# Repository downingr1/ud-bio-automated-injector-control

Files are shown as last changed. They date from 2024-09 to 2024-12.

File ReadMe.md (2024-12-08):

# **UD Automated Stereotaxic Injector**

 

> [Arduino Uno Wiring Diagram - Tinkercad](https://www.tinkercad.com/things/jYT1CjaT22d-november-2024-injector-control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)
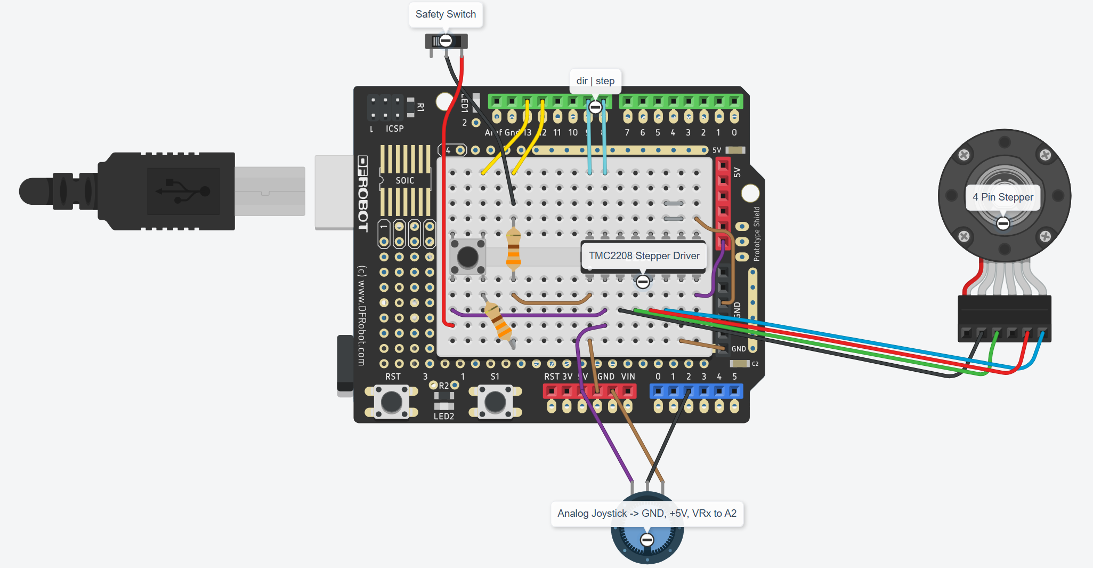
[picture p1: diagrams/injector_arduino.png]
 

This project has been developed by Owen Beer, Reilly Downing, and Megan LaBelle in support of Dr. Aaron Sathyanesan, Dr. Krishna Kidambi, and Mr. Abbas Raza with the University of Dayton Biology and Mechanical Engineering departments.

The Automated Injector is constructed with 3D printed housings, a Nema 8 stepper, an  Arduino starter kit, and various hardware. A full parts list is available as a part of this package.

### Purpose
Stereotaxic surgeries are a very common procedure in modern neuroscience. The University of Dayton Biology Department uses a GCaMP6f Ca2+ sensor to image the firing of neurons after injecting a virus into the brain of a living specimen. This virus causes the calcium indicators (GCaMP6f Ca2+) to be present, which can then be imaged using a specific wavelength laser. The injection of the virus however must be a very controlled process to avoid harming the specimen. Commonly, labs will buy syringe pumps with controllers that run around $3,000. The University of Dayton Biology department has assigned the team the task of designing this open-source alternative solution using readily available, cost-efficient components and an Arduino microcontroller.

### Repository Layout
This repository follows a simple structure.
  - The `diagrams` folder holds diagrams for wiring the arduino control board to the motor and switches. 
  - The `documentation` folder holds the spec sheet for the NEMA 8 Stepper motor as well as the assembly procedure for the automated injector.
  - The `injector_control_ino` folder contains the code used to program the arduino.
  - The `models` folder contains the CAD files used to design and print the injector housing
  - The `readme_images` folder contains the images shown below.

### Programming Arduino Using the Arduino IDE
The most user-friendly way to program and communicate with an Arduino is through the Arduino IDE. The latest IDE can be collected from [https://www.arduino.cc/en/software](https://www.arduino.cc/en/software). 

...

### Simply Executing Serial Communication in VS Code 
Reilly Donwing - September 2024

This documentation will detail how to install Microsoft Visual Studio Code and a Serial Monitor extension to simply establish serial communication with the injector.

1. Retrieve the appropriate installer for your operating system from [https://code.visualstudio.com/download](https://code.visualstudio.com/download)   
2. Run the installer, the default location is fine. Changing the location will not affect this process.  
3. Open VS Code  
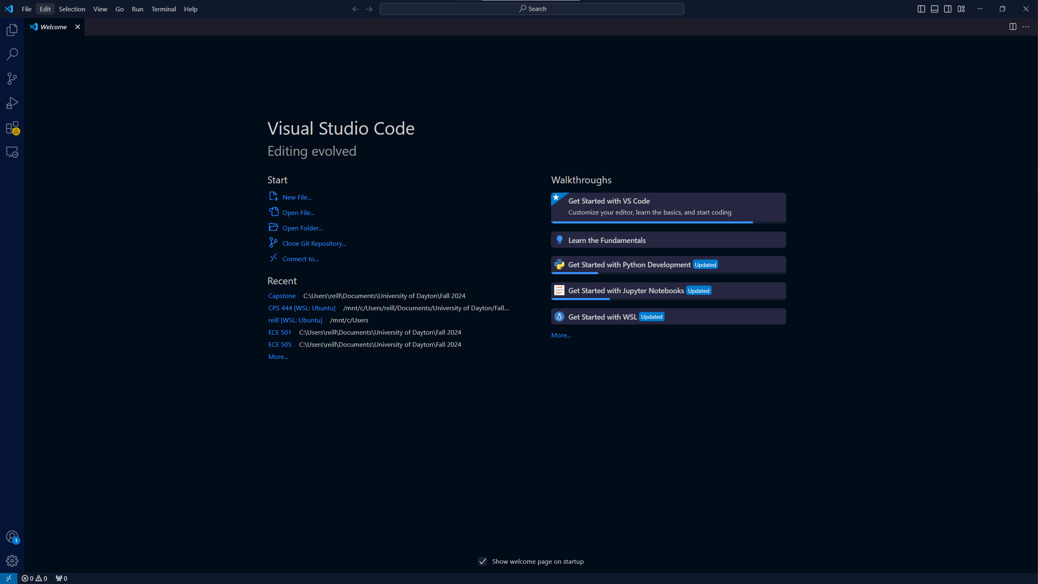
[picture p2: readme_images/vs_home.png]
  
4. Open the extensions menu ( ctrl \+ shift \+ x ) and search for Serial Monitor 
5. Select the extension marked as produced by Microsoft, then select install
6. At the top of the window, select Terminal > New Terminal
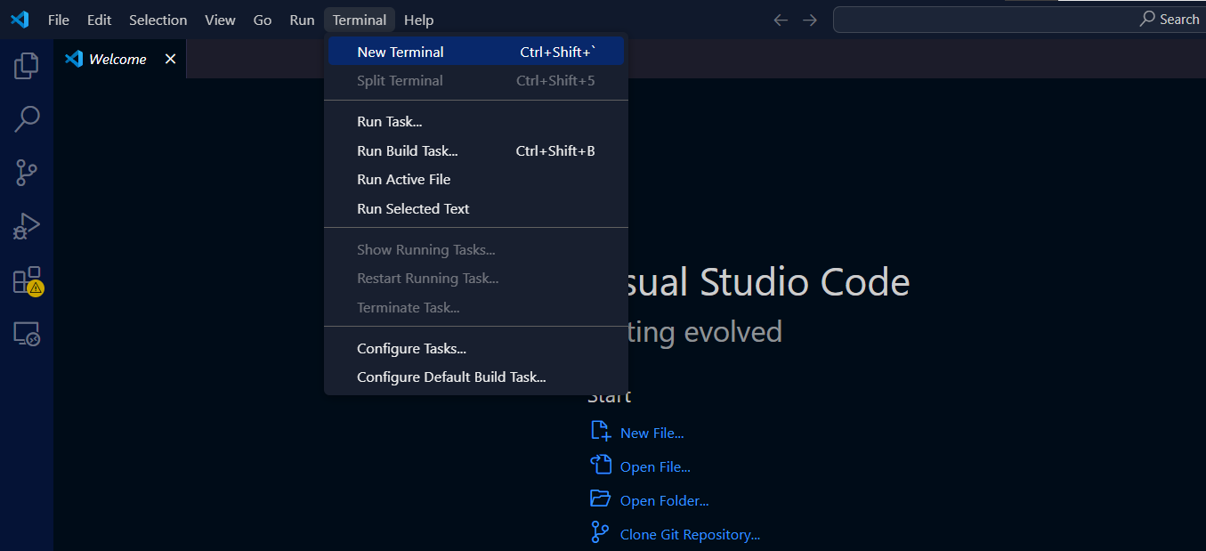
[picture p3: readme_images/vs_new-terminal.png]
  
7. In the new partition at the bottom of the window, select SERIAL MONITOR
8. With the device plugged in, ensure that the Port drop down has the correct port selected, ensure a buad rate of 115200, and select Start Monitoring.

If a message from the device is not displayed, press the reset button (physical button in corner of expansion board) on the Arduino controller.  
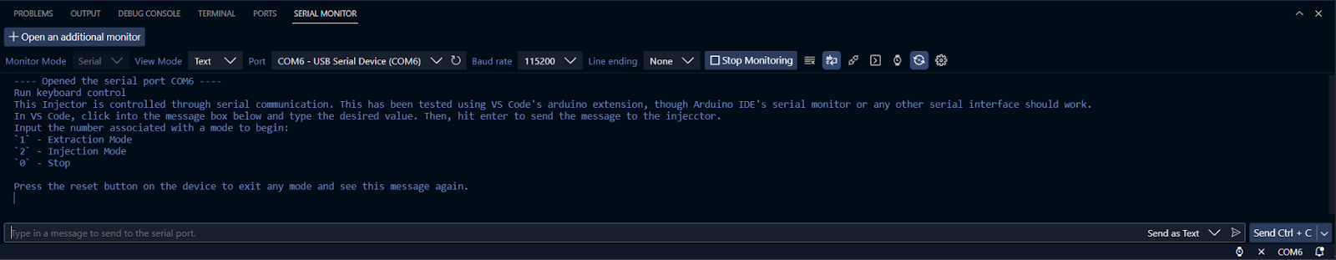
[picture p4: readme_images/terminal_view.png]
  
To send messages and interact with the device, click into the bar at the bottom of the Serial Monitor window. It should read `Type in a message to send to the serial port.` while waiting for an input.

### Programming Arduino in VS Code
Reilly Downing \- April 2024

This documentation will detail how to install Microsoft Visual Studio Code, and how to use the Arduino extension to establish serial communication with the injector.

1. Retrieve the appropriate installer for your operating system from [https://code.visualstudio.com/download](https://code.visualstudio.com/download)   
2. Run the installer, the default location is fine. Changing the location will not affect this process.  
3. Open VS Code  
4. Open the extensions menu ( ctrl \+ shift \+ x ) and search for Arduino  
5. Select the extension marked as produced by Microsoft, then select install  
6. If prompted, select to use Arduino CLI  
   1. If not prompted, open settings ( ctrl \+ , ), type ‘arduino’ into the search bar  
   2. Scroll down to see Arduino: **Use Arduino Cli**  
   3. Select the box to enable this

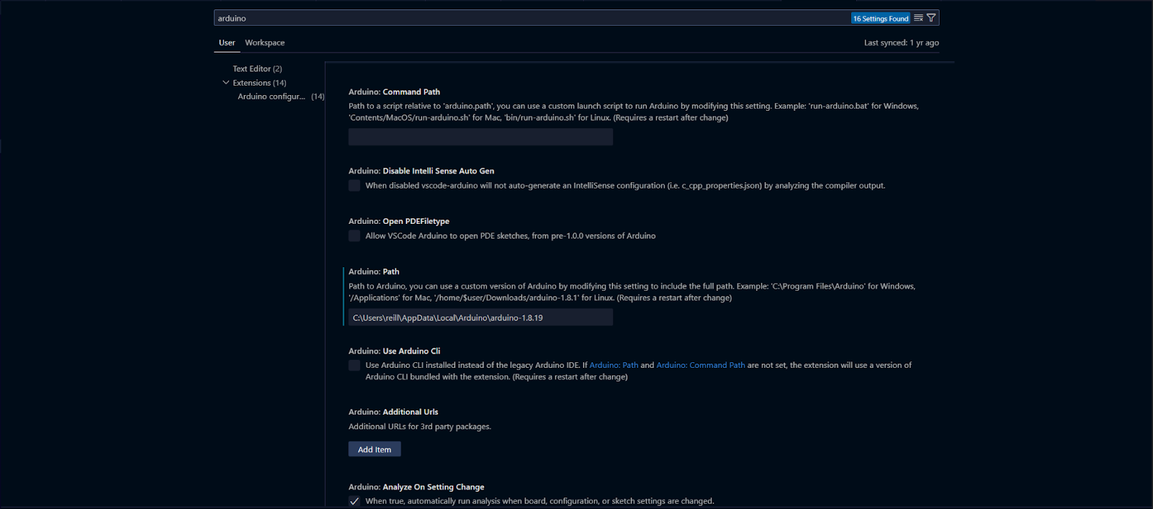
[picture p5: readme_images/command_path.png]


7. Restart the IDE (VS Code)  
8. Ensure the device is plugged into the computer using USB  
   1. Open the command search ( ctrl \+ shift \+ p )  
   2. Begin to type Arduino: Select Serial Port, click the command  
   3. Select the port with Uno R3 or USB Serial Device from the list  
      1. For Error regarding Serial Monitor Extension, return to step 6, double check the CLI use in settings, and restart the IDE, ensuring it has been stopped in task manager before reopening  
      2. if the error pops up after this, simply ignore it and run Arduino: Select Serial Port again  
9. The arduino.json configuration file should be created inside the .vscode directory of the current workspace, ensure this file exists or create it.
   1. Edit the json object to point to the injector control program, it should have the following form:
   ```json
   {
    "board": "arduino:avr:uno",
    "sketch": "injector_control_stepper\\injector_control.ino",
    "port": "COM4"
   }
   ```
10. Open injector_control.ino and select the verify then upload options from the arduino extensions up in the top right of the editor. On errors regarding missing libraries, ensure that the accel_stepper library is included in your arduino libraries path.

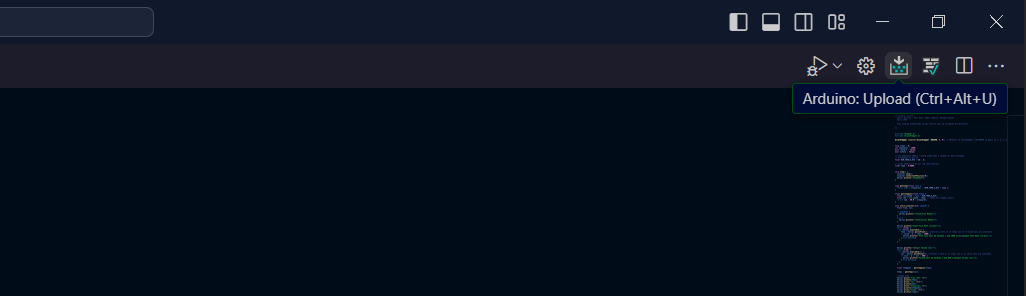
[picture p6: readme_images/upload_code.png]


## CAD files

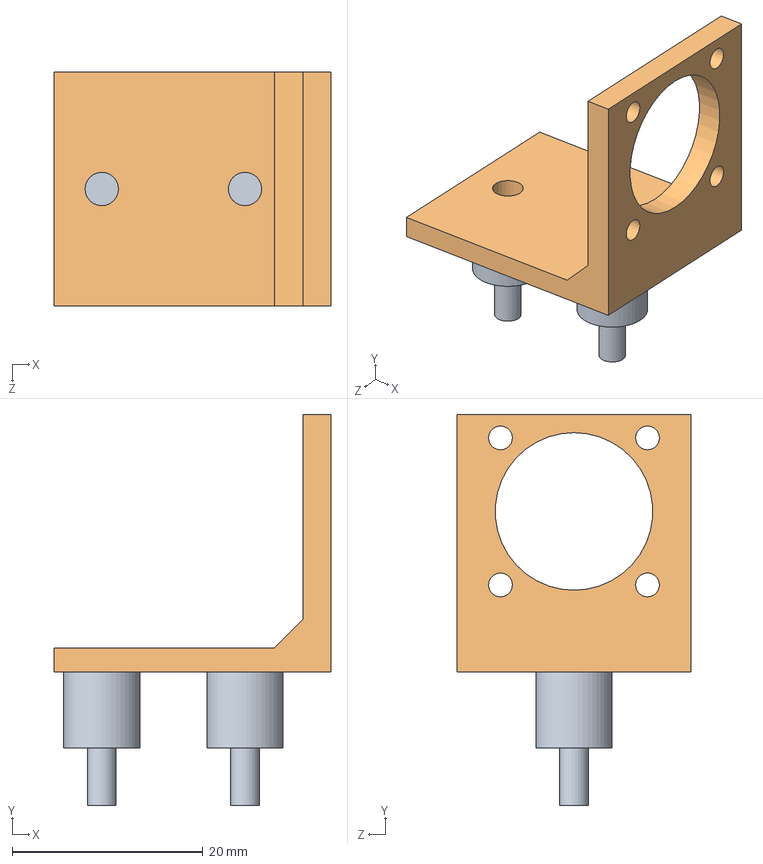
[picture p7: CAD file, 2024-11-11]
models/Currrent/Parts/Assem1.SLDASM
29.0 x 41.0 x 24.5 mm
Nema8 Mount
Vibration Idolator x 2

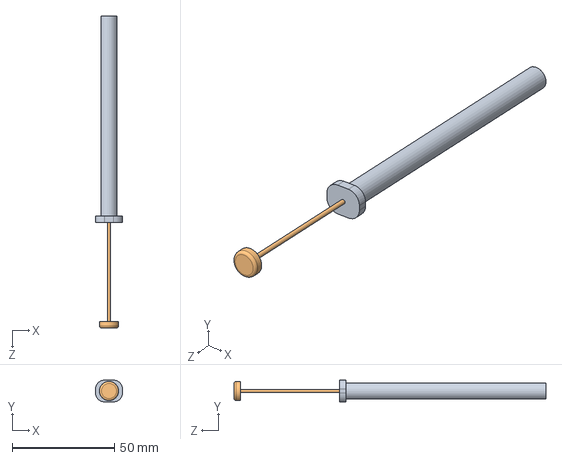
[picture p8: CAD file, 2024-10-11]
models/Currrent/Parts/SyringeAsm.SLDASM
13.2 x 10.7 x 152.3 mm
Plunger
syringe

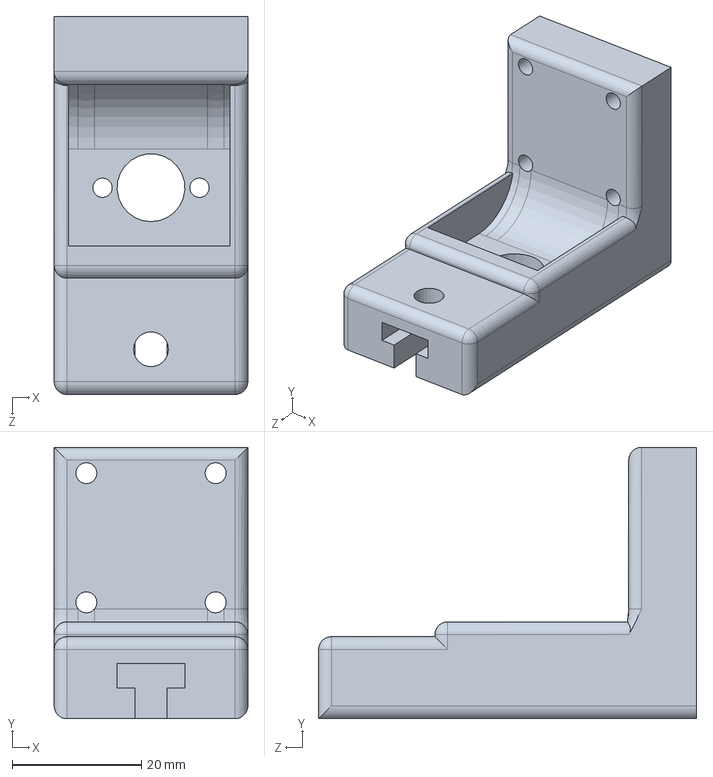
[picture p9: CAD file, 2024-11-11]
models/Currrent/3DPrintedParts/PlungerDriverB.SLDPRT
30.0 x 42.0 x 58.5 mm

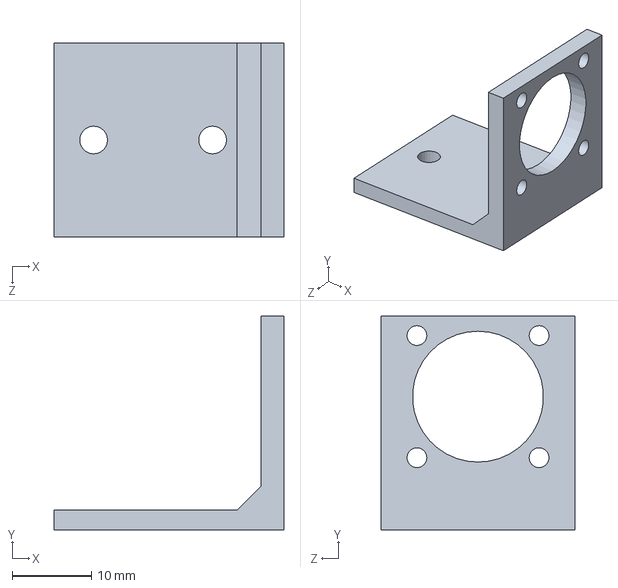
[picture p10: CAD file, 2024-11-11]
models/Currrent/Parts/Nema8 Mount.SLDPRT
29.0 x 27.0 x 24.5 mm

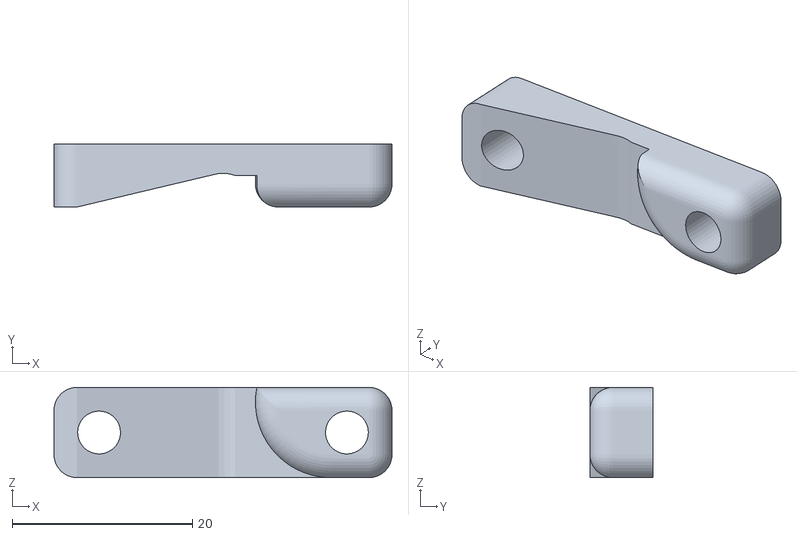
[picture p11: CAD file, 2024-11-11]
STL/RetentionMechanism.STL
37.5 x 7.00 x 10.00

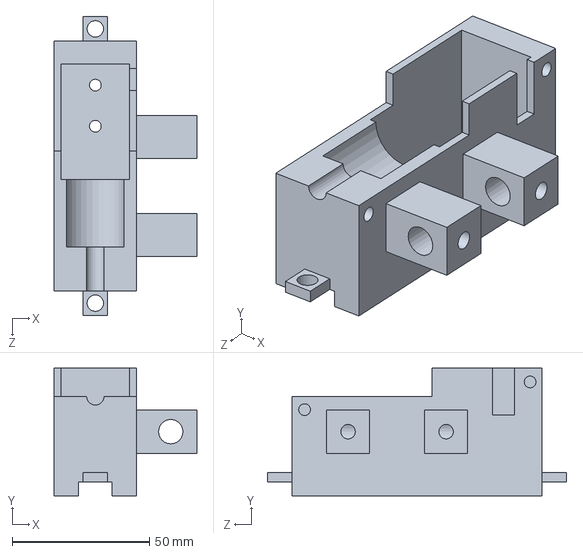
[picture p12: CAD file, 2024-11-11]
models/Currrent/3DPrintedParts/Motor Housing.SLDPRT
52.0 x 46.5 x 109.0 mm

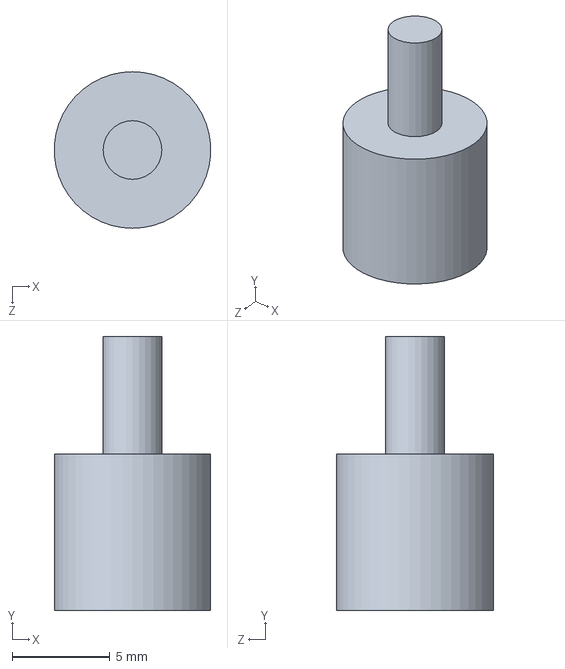
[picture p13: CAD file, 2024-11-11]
models/Currrent/Parts/Vibration Idolator.SLDPRT
7.98 x 14.0 x 8.00 mm

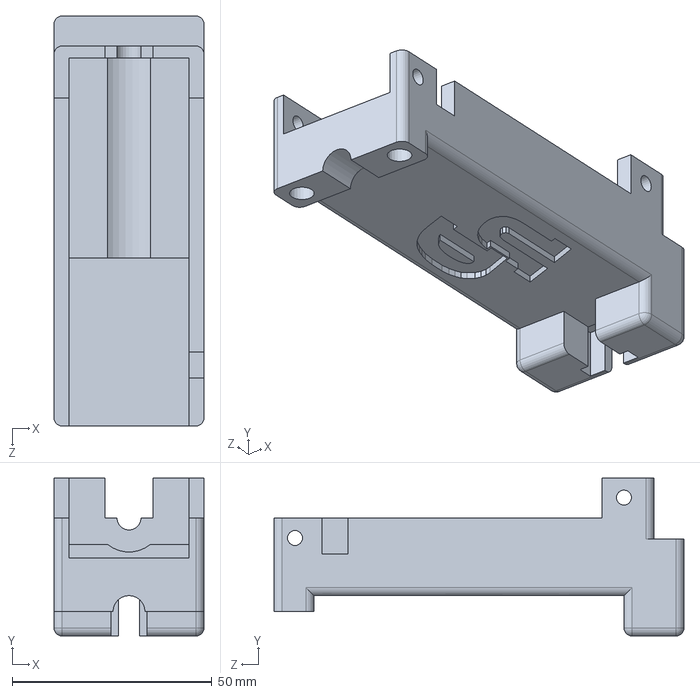
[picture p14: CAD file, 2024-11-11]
models/Currrent/3DPrintedParts/Cover.SLDPRT
37.5 x 39.5 x 102.5 mm

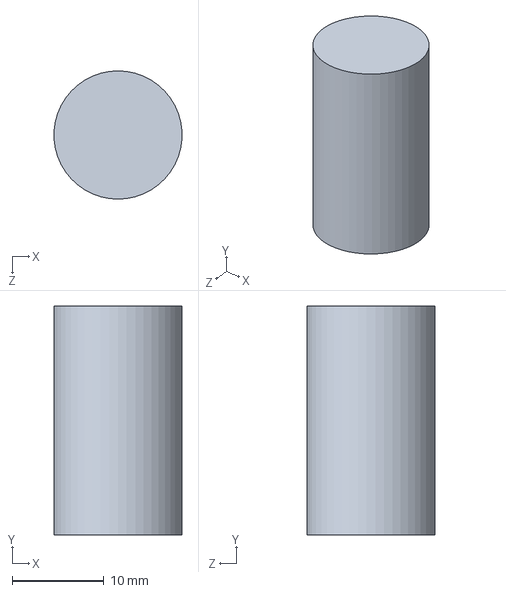
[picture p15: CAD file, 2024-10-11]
models/Currrent/Parts/Coupling.SLDPRT
14.0 x 25.0 x 14.0 mm

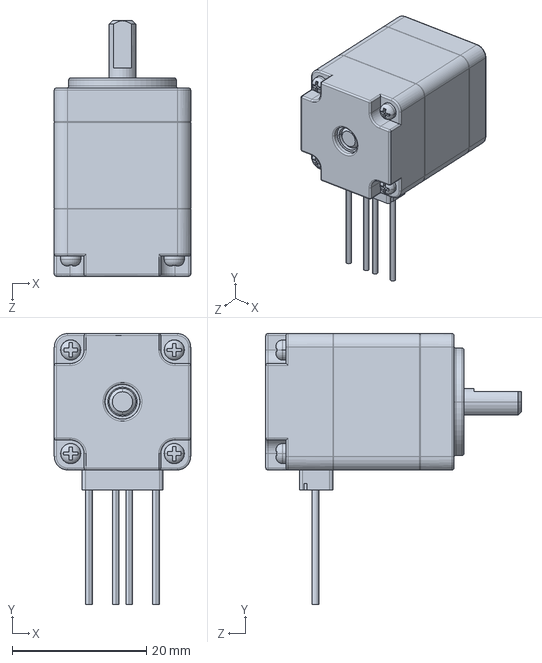
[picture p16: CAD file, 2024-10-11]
models/Currrent/Parts/8HS11-0204S.SLDPRT
20.3 x 40.3 x 38.0 mm

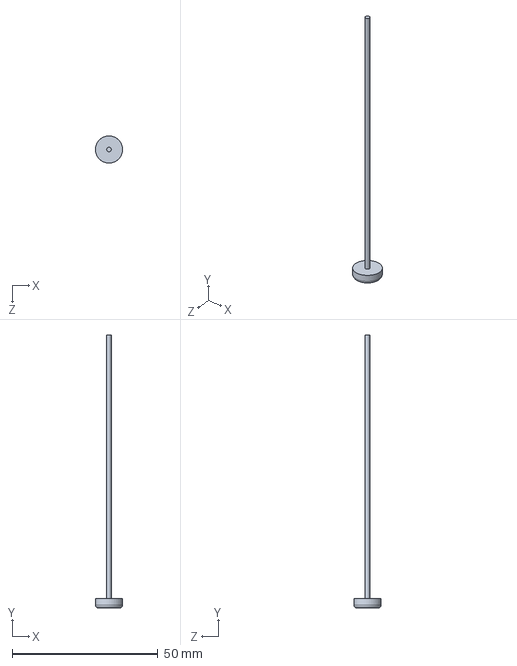
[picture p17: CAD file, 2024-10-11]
models/Currrent/Parts/Plunger.SLDPRT
9.33 x 93.7 x 9.33 mm

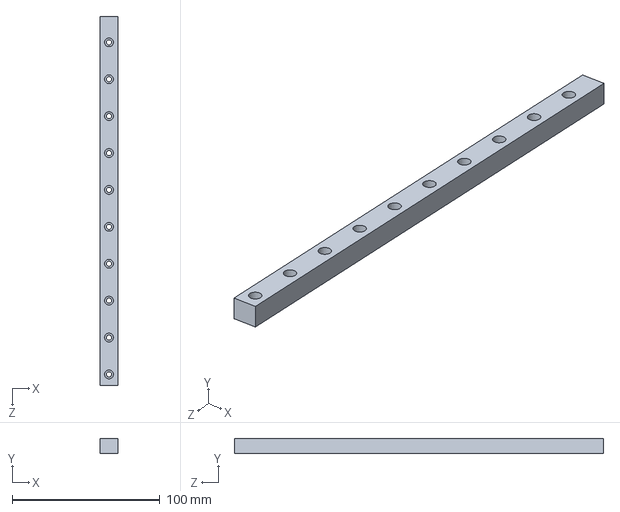
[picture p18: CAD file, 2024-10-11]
models/Currrent/Parts/Rail.SLDPRT
12.0 x 10.5 x 250.0 mm

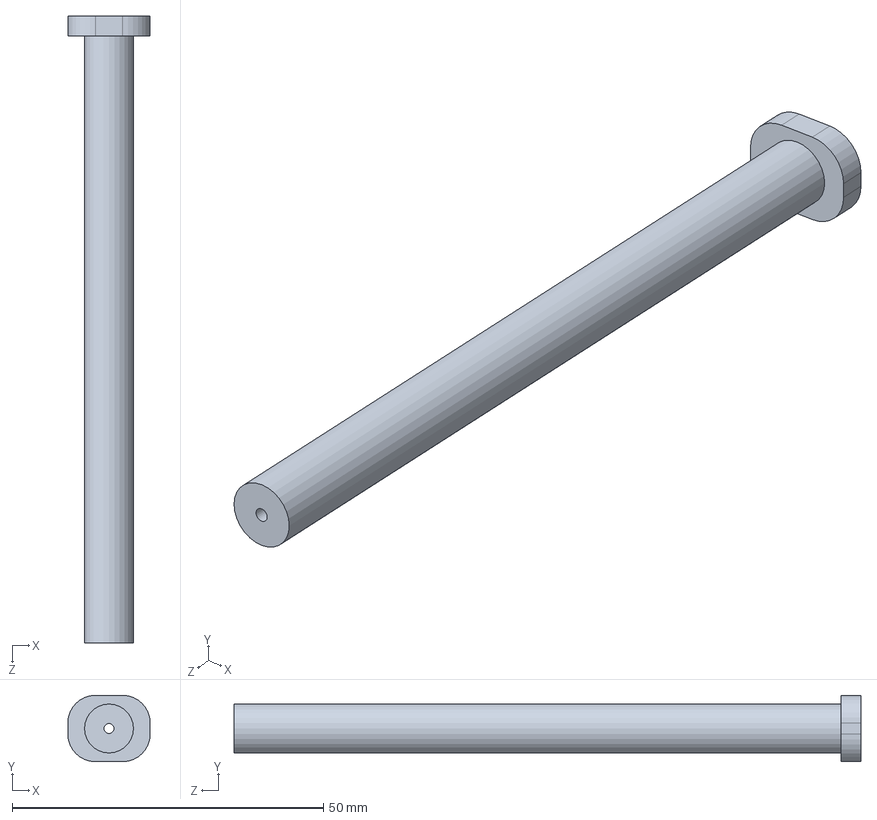
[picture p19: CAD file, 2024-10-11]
models/Currrent/Parts/syringe.SLDPRT
13.2 x 10.7 x 100.7 mm

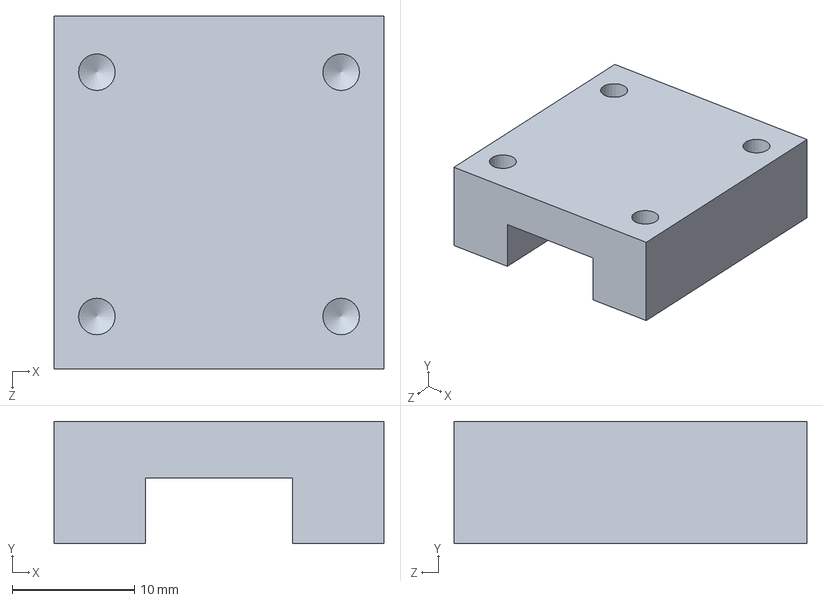
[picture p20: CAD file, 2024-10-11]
models/Currrent/Parts/Sliding Block.SLDPRT
27.0 x 10.0 x 28.9 mm

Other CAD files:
GCode/OwenBeer11-3.gcode.3mf
GCode/OwenBeer10-30.gcode.gcode.3mf
models/Currrent/3DPrintedParts/RetentionMechanism.SLDPRT
STL/Nema8 Mount.STL
STL/Cover.STL
STL/Motor Housing.STL
STL/PlungerDriverB.STL
models/Cover.SLDPRT
models/Currrent/Parts/6350K681_Flange Nut with 1 8 -41.7 Thread Size for Ultra-Precision Lead Screw.SLDPRT
models/Motor Housing.SLDPRT
models/PlungerDriverB.SLDPRT

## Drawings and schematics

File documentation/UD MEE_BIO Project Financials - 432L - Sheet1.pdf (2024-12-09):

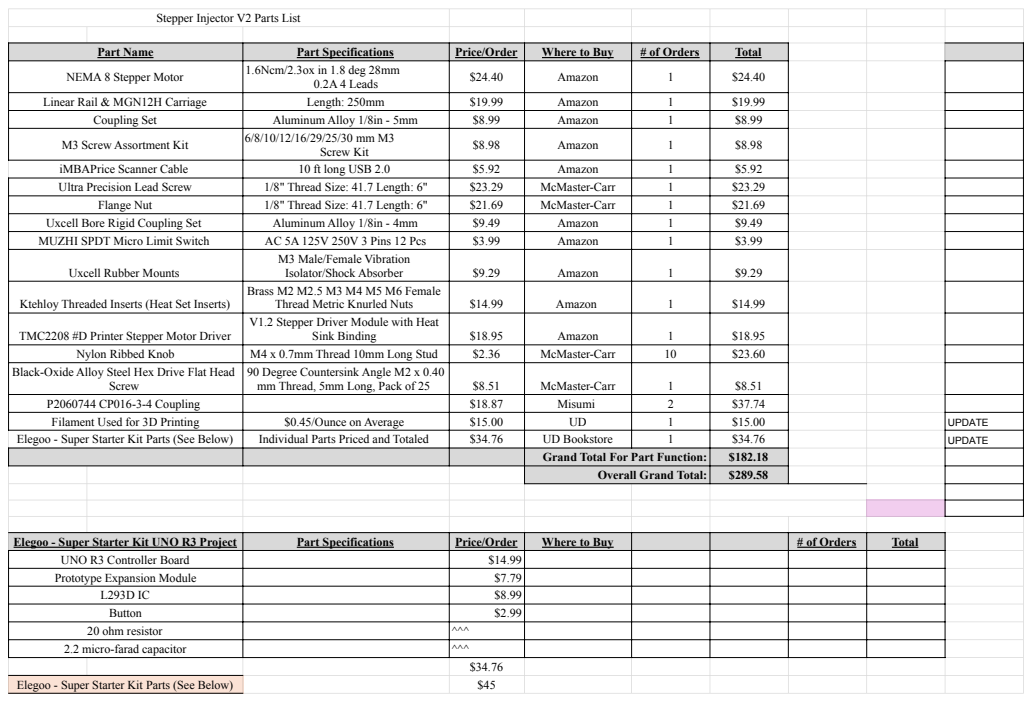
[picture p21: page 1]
iMBAPrice Scanner Cable; 10 ft long USB 2.0; Amazon; Filament Used for 3D Printing; $0.45/Ounce on Average; UPDATE; Elegoo - Super Starter Kit Parts (See Below); Individual Parts Priced and Totaled; UD Bookstore; Elegoo - Super Starter Kit UNO R3 Project; Part Specifications; Price/Order; Where to Buy; # of Orders; Total

Stepper Injector V2 Parts List

Part Name | Part Specifications | Price/Order | Where to Buy | # of Orders | Total
NEMA 8 Stepper Motor | 1.6Ncm/2.3ox in 1.8 deg 28mm 0.2A 4 Leads | $24.40 | Amazon | 1 | $24.40

Linear Rail & MGN12H Carriage | Length: 250mm | $19.99 | Amazon | 1 | $19.99

Coupling Set | Aluminum Alloy 1/8in - 5mm | $8.99 | Amazon | 1 | $8.99
M3 Screw Assortment Kit | 6/8/10/12/16/29/25/30 mm M3 Screw Kit | $8.98 | Amazon | 1 | $8.98

Ultra Precision Lead Screw | 1/8" Thread Size: 41.7 Length: 6" | $23.29 | McMaster-Carr | 1 | $23.29

Flange Nut | 1/8" Thread Size: 41.7 Length: 6" | $21.69 | McMaster-Carr | 1 | $21.69

Uxcell Bore Rigid Coupling Set | Aluminum Alloy 1/8in - 4mm | $9.49 | Amazon | 1 | $9.49
MUZHI SPDT Micro Limit Switch | AC 5A 125V 250V 3 Pins 12 Pcs | $3.99 | Amazon | 1 | $3.99
Uxcell Rubber Mounts | M3 Male/Female Vibration Isolator/Shock Absorber | $9.29 | Amazon | 1 | $9.29

Ktehloy Threaded Inserts (Heat Set Inserts) | Brass M2 M2.5 M3 M4 M5 M6 Female Thread Metric Knurled Nuts | $14.99 | Amazon | 1 | $14.99

TMC2208 #D Printer Stepper Motor Driver | V1.2 Stepper Driver Module with Heat Sink Binding | $18.95 | Amazon | 1 | $18.95

Nylon Ribbed Knob | M4 x 0.7mm Thread 10mm Long Stud | $2.36 | McMaster-Carr | 10 | $23.60

Black-Oxide Alloy Steel Hex Drive Flat Head Screw | 90 Degree Countersink Angle M2 x 0.40 mm Thread, 5mm Long, Pack of 25 | $8.51 | McMaster-Carr | 1 | $8.51

P2060744 CP016-3-4 Coupling | | $18.87 | Misumi | 2 | $37.74

Grand Total For Part Function: | $182.18

Overall Grand Total: | $289.58

UNO R3 Controller Board | $14.99
Prototype Expansion Module | $7.79

L293D IC | $8.99
Button | $2.99
20 ohm resistor | ^^^
2.2 micro-farad capacitor | ^^^

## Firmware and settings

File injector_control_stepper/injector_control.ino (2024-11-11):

/* Injector Control
  Reilly Downing - Owen Beer, Megan LaBelle, Naeamah Rabeea
  April 2024

  This program establishes serial control over an automated microinjector.
  
*/


#include <Stepper.h>
#include <AccelStepper.h>
 
AccelStepper injector(AccelStepper::DRIVER, 8, 9); // Defaults to AccelStepper::FULL4WIRE (4 pins) on 2, 3, 4, 5


long steps = 0;
int stepsprev = 1600;
bool restart = false;
bool safety = false;

// for hamiltion 7000.5 --could maybe make a lookup for both syringes
// 8.33333333 nL per mm
const float HAM_7000_5_DIV = 25 / 3;
const float HAM_7001_DIV = 50 / 3;

float syringe_div;

// given lead/pitch of our rod (mm/rotation)
float lead = 0.6096;


void stop() {
  injector.stop();
  injector.setCurrentPosition(0);
  Serial.println("Stopped\n");
}


long getsteps(float vol) {
  return (vol * stepsprev) / (syringe_div * lead );
}

float getsteppsec(float flow) {
  float lin_speed = flow / syringe_div;
  float rpm = lin_speed / lead; // handy for stepper motors
  return rpm / 60.0 * stepsprev;
}

void start_injector(bool inject) {
  float flow, vol;

  if (inject) {
    Serial.println("**Injection Mode**"); 
  }
  else {
    Serial.println("**Extraction Mode**");
  }
  
  Serial.println("Input Flow Rate (nL/min):"); 
  while (true) {
    if (Serial.available()) {                            
      flow = Serial.parseFloat(); //returns a zero if it times out or no valid ints are available
      if (flow < 1 || flow > 1000) {
        Serial.println("Flow rate must be between 1 and 1000 nL/min\nInput Flow Rate (nL/min):");
      } else {break;}
    }
  }
 
  
  Serial.println("\nInput Volume (nL):"); 
  while (true) {
    if (Serial.available()) {                            
      vol = Serial.parseFloat(); //returns a zero if it times out or no valid ints are available
      if (vol < 1 || vol > 500) {
        Serial.println("Volume must be between 1 and 500 nL\nInput Volume (nL):");
      } else {break;}
    }
  }
  
  float steppsec = getsteppsec(flow);

  steps = getsteps(vol);

  //Debug Info
  Serial.print("flow rate: \t");
  Serial.println(flow);
  Serial.print("vol: \t\t");
  Serial.println(vol); 
  Serial.print("Steps/sec: \t");
  Serial.println(steppsec);
  Serial.print("Steps: \t\t");
  Serial.println(steps);

  
  Serial.println("\nReady. Hit Physical Button to begin."); 
  
  while (true) {
    if (digitalRead(13)==HIGH) {        // Hangs until button is pressed
      while (digitalRead(13)==HIGH){
            // Hangs until button is released
      }
      break;
    }
  }
  if (inject) {
    Serial.println("Injecting...");
    injector.move(-steps);
  }
  else {
    Serial.println("Extracting...");
    injector.move(steps);
  }
  injector.setSpeed(steppsec);
  
  while( (digitalRead(12)==LOW || !inject) ) {   
    injector.runSpeedToPosition();

    if(digitalRead(13)==HIGH) {
      Serial.println("**\n**PAUSING - Press Button Again to Resume, Press Reset to Stop\n**\n");
      while(true){
        delay(1);
        if (digitalRead(13)==LOW) {   
          delay(1);     // tiniest debouncing code to prevent errant pausing
          while (digitalRead(13)==LOW){/* Hangs until button is Pressed*/}
          while(digitalRead(13)==HIGH){/* Hangs until button is released*/}
          delay(1);
          Serial.println("**\n**RESUMING \n**\n");
          break;
        }
      }
    }

    if (injector.currentPosition()==injector.targetPosition()) {
        injector.setCurrentPosition(0);
        restart = true;
        break;
    }
  }
  
  if (!restart) {
    injector.setCurrentPosition(0);
    safety = true;
  }

  steps = 0;
}

int xValue = 0; // To store value of the X axis
int yValue = 0; // To store value of the Y axis

int upthresh = 640;
int downthresh = 400;


void manual() {
  Serial.println("Begin Manual Control. Press the Physical Button to exit.");
  while(digitalRead(13)==LOW) {
      // read analog X and Y analog values
    xValue = analogRead(A2);

    if (xValue > upthresh) {
      
      float steppsec = getsteppsec(600);
      steps = getsteps(500);

      injector.move(-steps);
      injector.setSpeed(steppsec);

      while(digitalRead(12)==LOW && xValue > upthresh) {
        xValue = analogRead(A2);
        injector.runSpeedToPosition();
      }
    }
    if (xValue < downthresh) {
      float steppsec = getsteppsec(600);
      steps = getsteps(500);

      injector.move(steps);
      injector.setSpeed(steppsec);

      while(xValue < downthresh) {
        xValue = analogRead(A2);
        injector.runSpeedToPosition();
      }

    }
  }
  injector.setCurrentPosition(0);
  restart = true;
}

void select_syringe() {
  bool selected = false;
  Serial.println("Input the number associated with the desired syringe: ");
  Serial.println("`1` - Hamilton 7000.5 0.5uL");
  Serial.println("`2` - Hamilton 7001 1uL");
  Serial.println("`3` - Custom");
  Serial.println("`4` - Exit without changing");
  while (!selected) {
    if(Serial.available()){
      char val = Serial.read();
      switch(val)
      {
      case '1': // Mode to Fill the syringe
        syringe_div = HAM_7000_5_DIV;
        Serial.println("Hamilton 7000.5 0.5uL Selected.\n");
        selected = true;
        break;
      case '2': // Mode for injection
        syringe_div = HAM_7001_DIV;
        Serial.println("Hamilton 7001 1uL Selected.\n");
        selected = true;
        break;
      case '3':
        syringe_div = get_div();
        Serial.println("Custom syringe set.\n");
        selected = true;
        break;
      case '4':
        Serial.println("Syringe not updated.\n");
        selected = true;
        break;
      }
    }
  }
  restart = true;
}

float get_div() {
  float div;
  Serial.println("Input Custom Syringe Volume per Millimeter (nL/mm):"); 
  while (true) {
    if (Serial.available()) {                            
      div = Serial.parseFloat(); //returns a zero if it times out or no valid ints are available
      if (div < 1 || div > 1000) {
        Serial.println("Syringe gradation must be between 1 and 1000 nanoliters per linear millimeter.\nInput value (nL/mm):");
      } else {break;}
    }
  }
  return div;
}


void printInstructions() {
  Serial.println("Input the number associated with a mode to begin: ");
  Serial.println("`1` - Extraction Mode");
  Serial.println("`2` - Injection Mode");
  Serial.println("`3` - Manual Joystick Control");
  Serial.println("`4` - Select Syringe");
  Serial.println();
  Serial.println("Press the reset button on the device to exit any mode and see this message again.");
}

void setup() {
  Serial.begin(115200);      //Set Baud Rate (115200 default rate in VS Code Serial Monitor)
  syringe_div = HAM_7000_5_DIV;
  Serial.println("Run keyboard control");
  Serial.println("This Injector is controlled through serial communication. This has been tested using VS Code's arduino extension, though Arduino IDE's serial monitor or any other serial interface should work.");
  Serial.println("In VS Code, click into the message box below and type the desired value. Then, hit enter to send the message to the injector.");
  Serial.println("Default Syringe: 0.5uL");
  printInstructions();
  injector.setCurrentPosition(0);
  injector.setMaxSpeed(8000);
}



void loop() {
  injector.setCurrentPosition(0);
  if(restart){
    Serial.println("Finished\n");
    printInstructions();
    restart = false;
  } else if (safety) {
    Serial.println("Safety tripped, please extract and reset.\n");
    printInstructions();
    safety = false;
  }
  if(Serial.available()){
    char val = Serial.read();
    if(val != -1)
    {
      switch(val)
      {
      case '1': // Mode to Fill the syringe
        start_injector (false);   
        break;
      case '2': // Mode for injection
        start_injector (true);
        break;
      case '3':
        manual();
        break;
      case '4':
        select_syringe();
        break;

      }
    }
    else stop();
  }
}

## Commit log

2024-09-12 Added code for external off switch
2024-10-01 limit switch
2024-10-09 arduino diagram
2024-10-09 assembly proc
2024-10-11 Reorganized and updated CAD files
    [6350K681_Flange Nut with 1 8 -41.7 Thread Size for Ultra-Precision Lead Screw.SLDPRT, 8HS11-0204S.SLDPRT, 8HS11-0204S.STEP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]
2024-11-08 Add Syringe Selection and Debounces Pausing
2024-11-11 updated models
    [6350K681_Flange Nut with 1 8 -41.7 Thread Size for Ultra-Precision Lead Screw.SLDPRT, 8HS11-0204S.STEP, Assem1.SLDASM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]
